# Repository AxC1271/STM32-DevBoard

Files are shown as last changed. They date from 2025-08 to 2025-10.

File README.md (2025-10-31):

# STM32 MCU Board

## 📖 Introduction
This repository is my first ever PCB design project. After working on projects that involved more digital circuits and RTL scripting, I've always wanted to build my own boards, specifically FPGA boards. However, I want to start on something simpler so I can understand the inner workings of PCB design, decision choices, and general concepts that are crucial to a functional STM32 board.

## 🛠️ Design Approach
Given that this is just a basic guide to designing, laying out, and manufacturing a simple STM32 board, this PCB will only offer a single USB port, an I2C interface, an SWD interface, and a UART interface. The specific processor chip that we are using is the STM32F103C8Tx, which uses an `ARM Cortex-M3 processor`. 

### ⚡ Power Regulator Circuit
<p align="center">
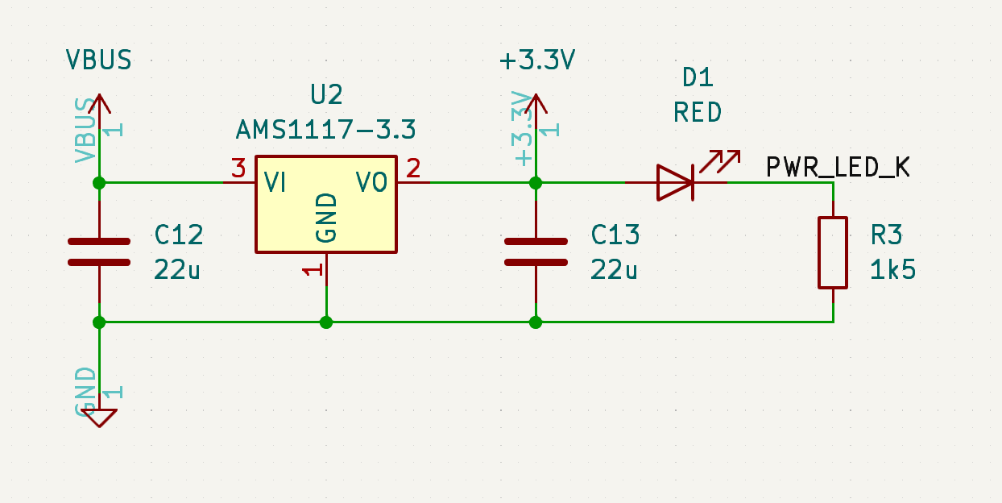
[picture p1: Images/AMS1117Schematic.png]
    
</p>
<p align="center">
    <em> LDO-Based Power Regulator Circuit.</em>
</p>

Here we have the external USB-B micro port that interfaces with our STM32 microcontroller. In order to use `VBUS` coming from this port, I stepped down any input voltage down to 3.3V using the **AMS1117** chip, which requires two `22uF` capacitors according to its datasheet, one at the input and one at the output. At the output, the 3.3V signal is then passed through an LED with a current limiting resistor as a visual indicator that the 3.3V source is present at the output.

<br />
Quick note about the shield option being ignored, generally the shield pin is to connect the board to an external chassis but because this is a standalone board, that's why it's ignored.

### 🔲 STM32F103C8T6 MCU
<p align="center">
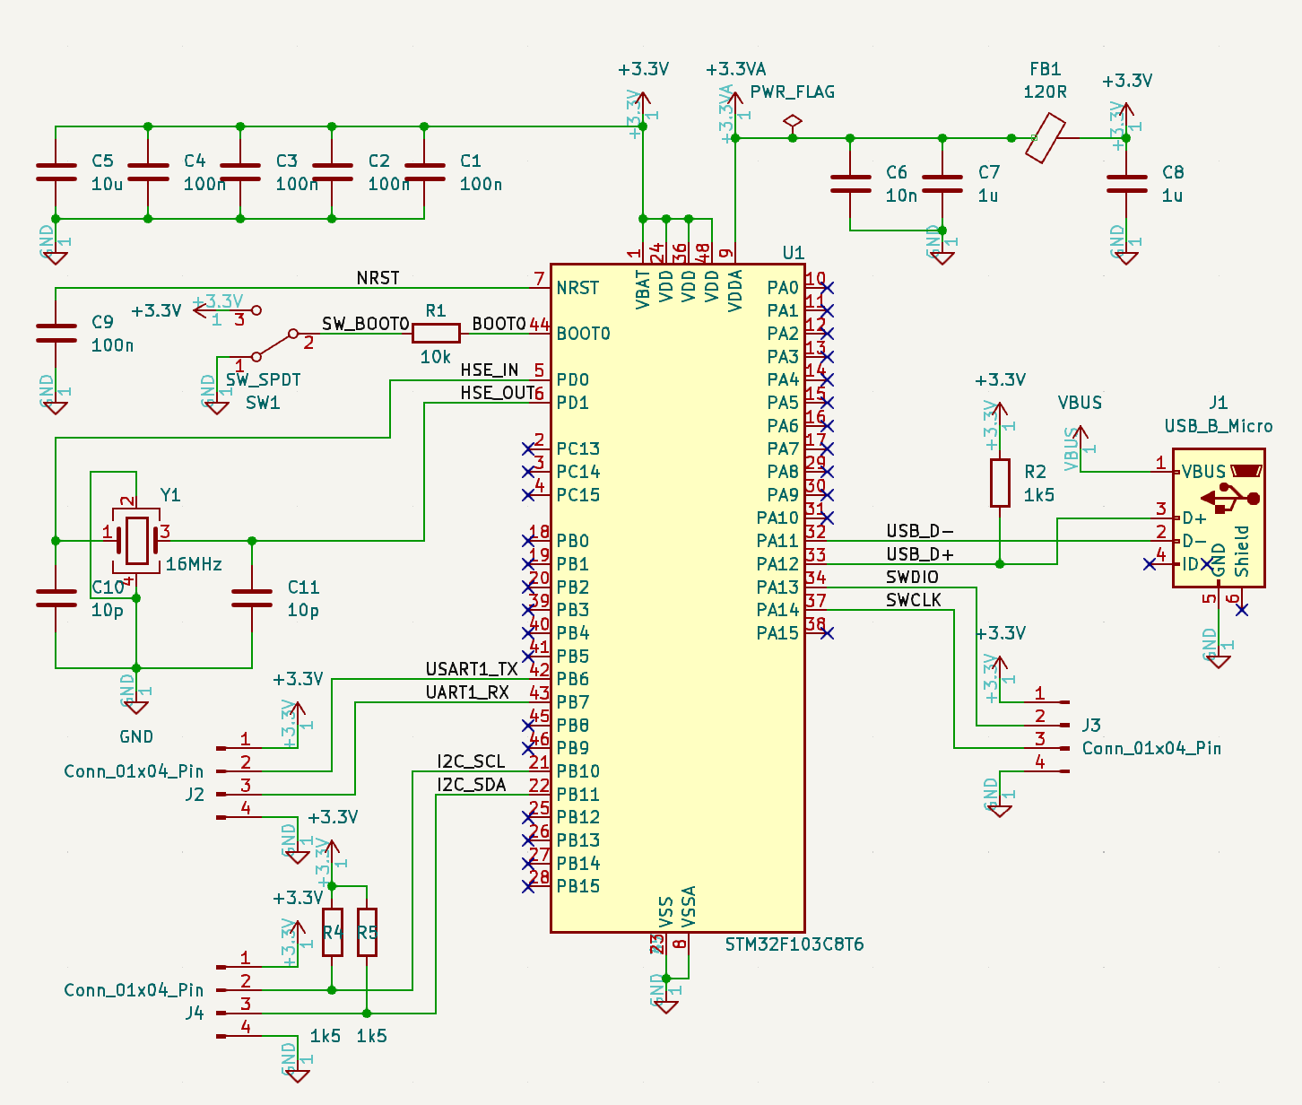
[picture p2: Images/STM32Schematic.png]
    
</p>
<p align="center">
    <em>MCU Schematic with USB-B Micro Interface.</em>
</p>

First and foremost, there needs to be capacitors between the 3.3V source and ground. Since this specific STM32 microcontroller has 4 **VDD** pins, there must generally be a `100 nF` capacitor in parallel for each of these pins. These capacitors act as `decoupling capacitors`, ensuring a steady voltage supply to each VDD pin. In addition, a bulk capacitor with a value of `4.7 uF` is also placed in parallel to the decoupling capacitors to handle lower-frequency current swings, while the decoupling capacitors handle the higher frequency noise and transients.

## 🧩 PCB Layout

<p align="center">
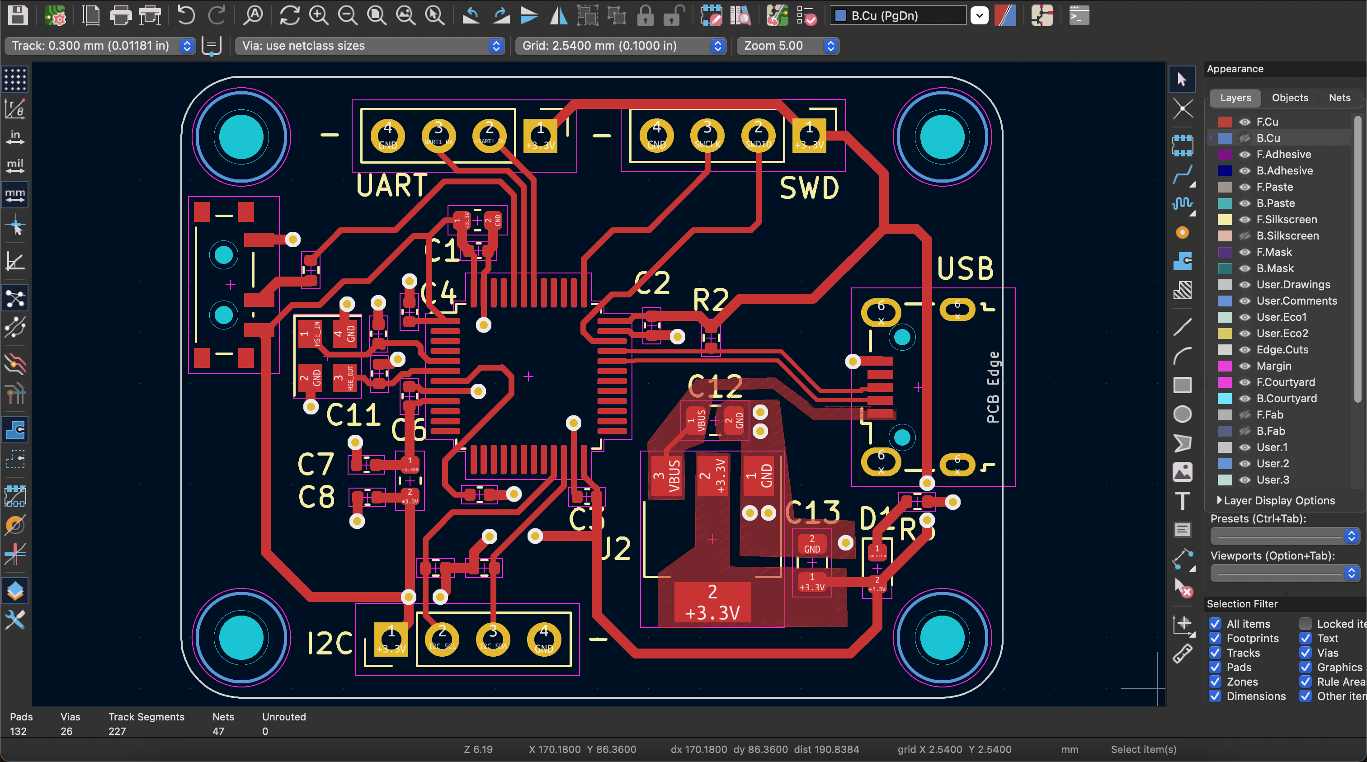
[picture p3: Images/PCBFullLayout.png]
    
</p>
<p align="center">
    <em> Signal traces on the STM32 board, with power traces being 0.5mm while ordinary traces are kept at 0.3mm. Vias are used for ground traces. </em>
</p>

In general, vias are used to link ground pins to the ground plane. Most signals are routed on the top copper layer, with a couple of vias used to prevent signal crossing especially with the 3.3V bus. 
A copper pour was used near the voltage regulator to create ground and power planes whilst also reducing EMI and improving signal integrity.

Quick note: to further increase the stability of a 2-layer board like this, it is recommended to add as much stitching vias as possible, on top of adding a ground pour on the top layer. This is to decrease
the distance that sensitive signals have to travel to get to ground, reducing the inductance and therefore maximizing signal integrity.

## 🖼️ 3D View

<p align="center">
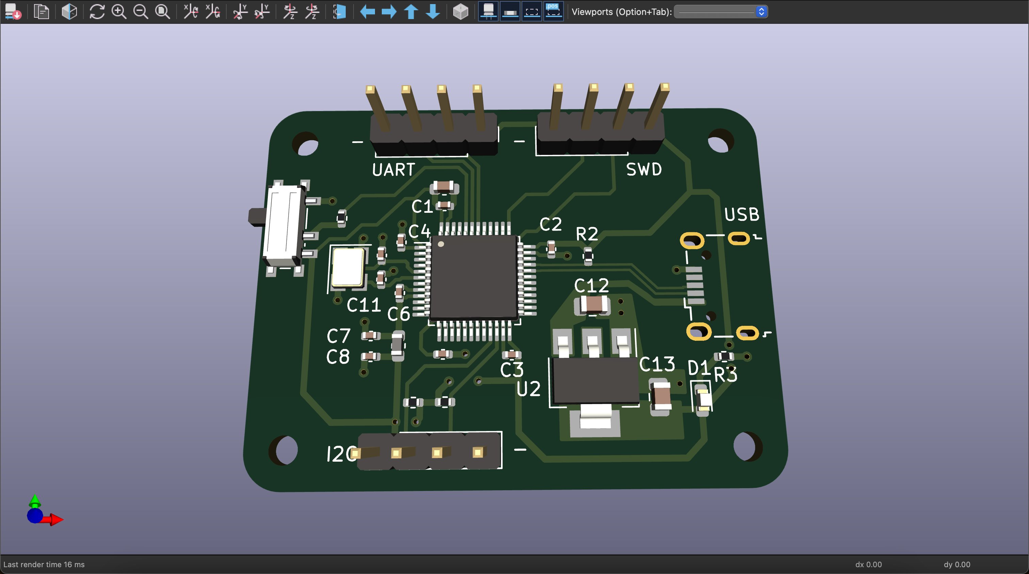
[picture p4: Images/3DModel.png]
    
</p>
<p align="center">
    <em> Front copper layer with all signal traces and silkscreens. </em>
</p>

## 🧪 Physical Board / Functionality

After passing a design rule check on KiCAD, it's time to send the files to a PCB manufacturer to get my board assembled. For this specific board, I'm using `JLCPCB`'s services to get my board manufactured. 

<p align="center">
    
</p>
<p align="center">
    <em>Manufactured Board from JLCPCB.</em>
</p>

Unfortunately, I was unable to find the USB micro-B ports for these boards, but I still want to be able to program it using an ST-Linker that I found off of Amazon for roughly `$9`. 

## 💻 Code

To test the UART interface of this STM32 board, I'll write a simple UART transceiver on my Basys3 FPGA board to interface with it.

UART Receiver:
```VHDL
library IEEE;
use IEEE.STD_LOGIC_1164.ALL;
use IEEE.NUMERIC_STD.ALL;

entity uart_rx is
    generic (
        clk_ticks: integer := 54 -- taken from (100_000_000 / 115200) / 16 = 54.25 ticks
        );
    port ( 
        clk : in STD_LOGIC;
        rst : in STD_LOGIC;
        rx : in STD_LOGIC;
        byte : out STD_LOGIC_VECTOR (7 downto 0);
        write : out STD_LOGIC
        );
end uart_rx;

architecture Behavioral of uart_rx is
    -- define internal signals here
    type rx_state is (IDLE, START, DATA, STOP); -- defined states
    signal curr_state : rx_state := IDLE; -- initial state
    
    signal baud_clk : STD_LOGIC := '0';
    signal byte_i : STD_LOGIC_VECTOR(7 downto 0) := (others => '0');
    
begin
    -- define internal processes here
    
    -- first process is a clock generator that generates an oversampled
    -- clock signal to check for the rx signal
    clk_generator : process(clk, rst) 
        variable clk_count : integer range 0 to clk_ticks := 0;
    begin 
        if rst = '1' then
            clk_count := 0;
            baud_clk <= '0';
        elsif rising_edge(clk) then
            if clk_count = clk_ticks then
                clk_count := 0;
                baud_clk <= '1'; -- set high when clk count reaches 54
            else
                clk_count := clk_count + 1;
                baud_clk <= '0';
            end if;
        end if;
    end process;
    
    -- second process handles the state machine logic
    rx_FSM : process(clk, rst) 
        variable bit_count : integer range 0 to 7 := 0; -- check for where we are in the data word
        variable bit_duration : integer range 0 to 15 := 0; -- check if a logic level has stayed steady
    begin
        if rst = '1' then
            byte_i <= (others => '0'); -- reset data bus
            curr_state <= IDLE;
            bit_count := 0;
            bit_duration := 0;
            write <= '0';
        elsif rising_edge(clk) then
            if baud_clk = '1' then
                case curr_state is
                    when IDLE =>
                        byte_i <= (others => '0');
                        bit_count := 0;
                        bit_duration := 0;
                        write <= '0';
                        -- if the rx line gets pulled low then
                        if rx = '0' then
                            curr_state <= START;
                        end if;
                    when START =>
                        write <= '0';
                        if rx = '0' then
                            if bit_duration = 7 then
                                curr_state <= DATA;
                                bit_duration := 0;
                            else
                                bit_duration := bit_duration + 1;
                            end if;
                        else
                            curr_state <= IDLE;
                        end if;
                    when DATA =>
                        write <= '0';
                        if (bit_duration = 15) then                
                                byte_i(bit_count) <= rx;     
                                bit_duration := 0;
                                if (bit_count = 7) then -- we got 8 bits             
                                    curr_state <= STOP;
                                    bit_duration := 0;
                                else
                                    bit_count := bit_count + 1;
                                end if;
                            else
                                bit_duration := bit_duration + 1;
                            end if;
                    when STOP =>
                        if (bit_duration = 15) then      
                            if rx = '1' then  -- validate stop bit is HIGH
                                byte <= byte_i;
                                write <= '1';    
                                curr_state <= IDLE;
                            else
                            -- Invalid stop bit, frame error - reset
                                curr_state <= IDLE;
                            end if;
                        else
                            bit_duration := bit_duration + 1;
                        end if;
                    when others =>
                        curr_state <= IDLE;
                end case;
            end if;
        end if;
    end process;

end Behavioral;
```

Now we can write the C++ code for the STM32 to pass in some serial data to the Basys3 board and vice versa. We will interface using PlatformIO and write some firmware for the STM32 to transmit some characters to the FPGA. This is just one test code example:

```C++
#include <Arduino.h>
#include <HardwareSerial.h>

// TX pin: PB6, RX pin: PB7 (for UART1)
HardwareSerial Serial1(PB7, PB6); // RX, TX pins

unsigned long lastByteTime = 0;
const unsigned long byteInterval = 1000; // send each byte every 1 second
const char message[] = "Hello "; // message to send
int currentByteIndex = 0;
const int messageLength = 6; 

void setup() {
  Serial1.begin(115200); // uart receiver has baud rate of 115200
  
  Serial.begin(115200);
  Serial.println("STM32 UART Transmitter Started");
  Serial.println("Transmitting 'Hello' - one byte per second");

}

void loop() {
  if (millis() - lastByteTime >= byteInterval) {
    
    char currentByte = message[currentByteIndex];
    Serial1.write(currentByte);
    
    Serial.print("Transmitted byte: '");
    Serial.print(currentByte);
    Serial.print("' (ASCII: ");
    Serial.print((int)currentByte);
    Serial.println(")");

    digitalWrite(PC13, !digitalRead(PC13));
    
    currentByteIndex++;
    if (currentByteIndex >= messageLength) {
      currentByteIndex = 0; 
      Serial.println("--- Message complete, restarting ---");
    }
    
    lastByteTime = millis();
  }
  
  delay(10);
}
```

## 🎥 Video Demo

The first **[video demo](https://youtube.com/shorts/mgw7LnCIHqA)**  shows the FPGA receiver interacting with my Macbook via the `USB-to-Serial bridge`. The purpose of this
is to see the board behaving correctly from a known source using the terminal. Once the receiver's behavior has been validated,
then we can integrate the STM32 board and test its functionality.

Here's the **[video demo](https://youtube.com/shorts/DqSGexJcCeM)** showing the Basys3 taking the data bytes through a PMOD port from the STM32 MCU board to show that communication is 
indeed possible from my fabricated board. This required changing the RX pin on the FPGA to receive the byte.

---

Thanks for stopping and reading until the very end and I hope you learned something new from this README file!

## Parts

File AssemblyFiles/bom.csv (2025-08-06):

Comment | Designator | Footprint | LCSC Part # | Quantity
100nF | C1 C2 C3 C4 C9 | C_0402_1005Metric | C1525 | 5
10uF | C5 | C_0603_1608Metric | C19702 | 1
10nF | C6 | C_0402_1005Metric | C15195 | 1
1uF | C7 C8 | C_0402_1005Metric | C52923 | 2
10pF | C10 C11 | C_0402_1005Metric | C32949 | 2
22uF | C12 C13 | C_0805_2012Metric | C45783 | 2
RED LED | D1 | LED_0603_1608Metric | C2286 | 1
120R@100MHz Ferrite Bead | FB1 | L_0603_1608Metric | C1030 | 1
USB Micro-B | J1 | USB_Micro-B_Wuerth_629105150521 | C132563 | 1
1x4 2.54mm Pin Header | J2 J3 J4 | PinHeader_1x04_P2.54mm_Vertical | C124378 | 3
10kΩ | R1 | R_0402_1005Metric | C25744 | 1
1.5kΩ | R2 R3 R4 R5 | R_0402_1005Metric | C25867 | 4
SPDT Slide Switch | SW1 | SW_SPDT_PCM12 | C221841 | 1
STM32F103C8T6 | U1 | LQFP-48_7x7mm_P0.5mm | C8734 | 1
AMS1117-3.3V | U2 | SOT-223-3_TabPin2 | C6186 | 1
16MHz Crystal 4-pin | Y1 | Crystal_SMD_3225-4Pin_3.2x2.5mm | C13738 | 1

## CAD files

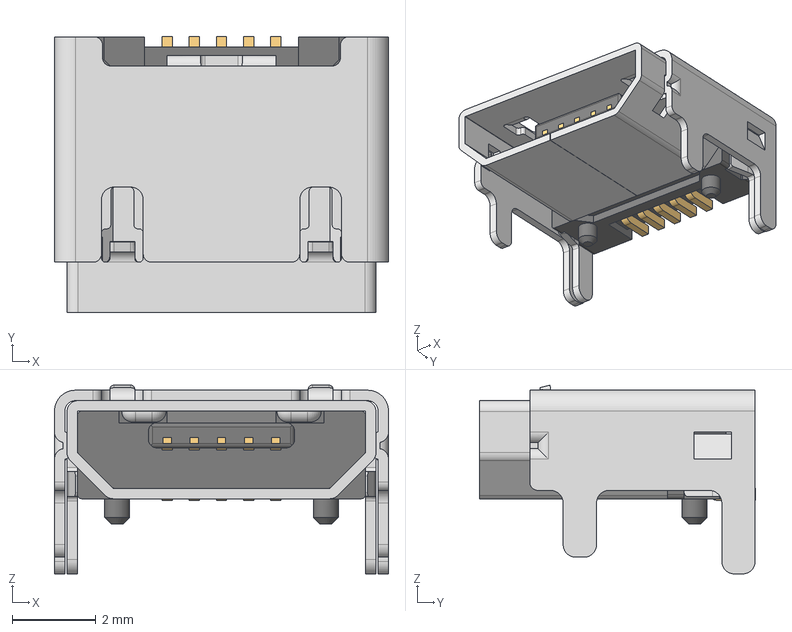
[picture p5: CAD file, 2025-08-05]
KiCADFiles/629105150521 (rev1).stp
8.00 x 6.60 x 4.52 mm
629105150521_Housing
629105150521_Pin1 x 4
629105150521_Pin2
629105150521_Shielding2
629105150521_Shielding

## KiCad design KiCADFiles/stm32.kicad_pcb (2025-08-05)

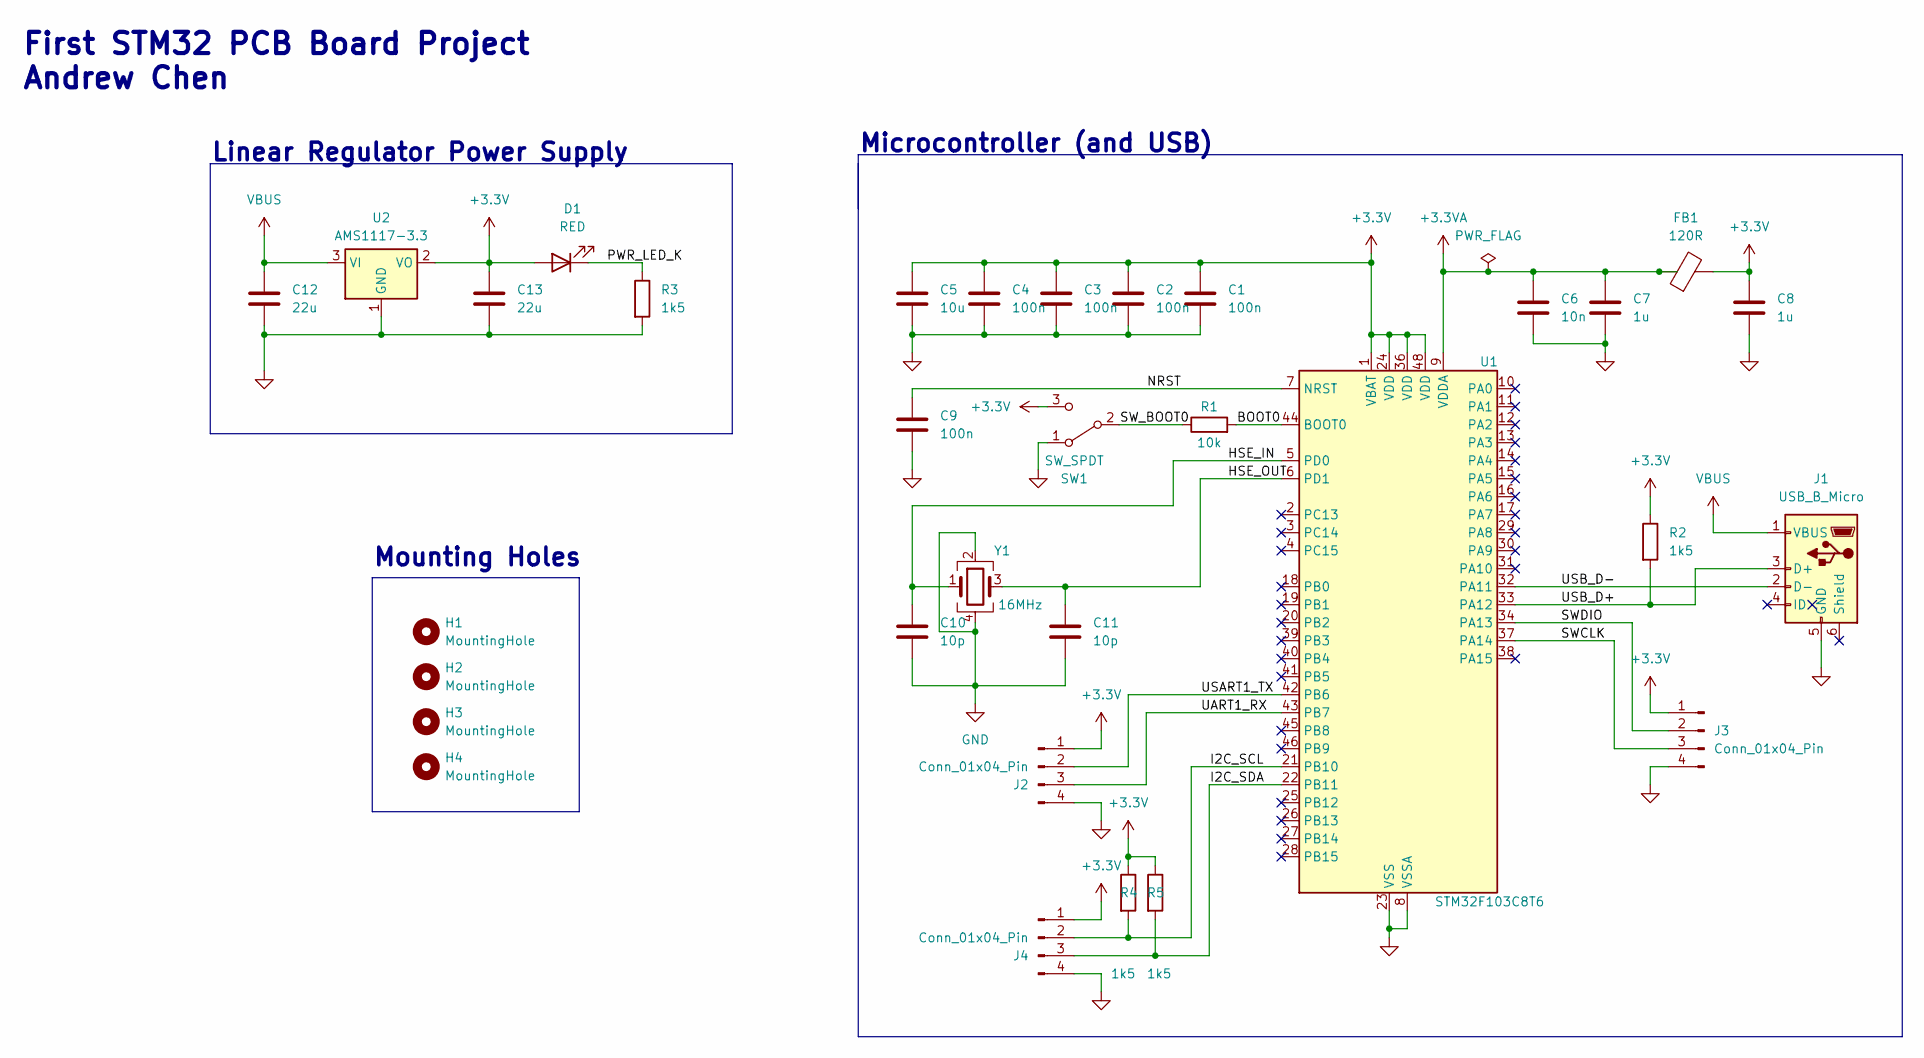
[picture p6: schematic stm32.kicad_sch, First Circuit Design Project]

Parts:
C1, C2, C3, C4, C9: 100n; C_0402_1005Metric
C5: 10u; C_0603_1608Metric
C6: 10n; C_0402_1005Metric
C7, C8: 1u; C_0402_1005Metric
C10, C11: 10p; C_0402_1005Metric
C12, C13: 22u; C_0805_2012Metric
D1: RED; LED_0603_1608Metric
FB1: 120R; L_0603_1608Metric
H1, H2, H3, H4: MountingHole; MountingHole_2.2mm_M2
J1: USB_B_Micro; USB_Micro-B_Wuerth_629105150521
J2, J3, J4: Conn_01x04_Pin; PinHeader_1x04_P2.54mm_Vertical
R1: 10k; R_0402_1005Metric
R2, R3, R4, R5: 1k5; R_0402_1005Metric
SW1: SW_SPDT; SW_SPDT_PCM12
U1: STM32F103C8T6; LQFP-48_7x7mm_P0.5mm
U2: AMS1117-3.3; SOT-223-3_TabPin2
Y1: 16MHz; Crystal_SMD_3225-4Pin_3.2x2.5mm

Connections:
+3.3V: C1.1, C2.1, C3.1, C4.1, C5.1, C8.1, C13.1, D1.2 (A), FB1.2, J2.1, J3.1, J4.1, R2.1, R4.1, R5.1, SW1.3 (C), U1.1 (VBAT), U1.24 (VDD), U1.36 (VDD), U1.48 (VDD), U2.2 (VO)
+3.3VA: C6.1, C7.1, FB1.1, U1.9 (VDDA)
/BOOT0: R1.2, U1.44 (BOOT0)
/HSE_IN: C10.1, U1.5 (PD0), Y1.1
/HSE_OUT: C11.1, U1.6 (PD1), Y1.3
/I2C_SCL: J4.2, R4.2, U1.21 (PB10)
/I2C_SDA: J4.3, R5.2, U1.22 (PB11)
/NRST: C9.1, U1.7 (NRST)
/PWR_LED_K: D1.1 (K), R3.1
/SWCLK: J3.3, U1.37 (PA14)
/SWDIO: J3.2, U1.34 (PA13)
/SW_BOOT0: R1.1, SW1.2 (B)
/UART1_RX: J2.3, U1.43 (PB7)
/USART1_TX: J2.2, U1.42 (PB6)
/USB_D+: J1.3 (D+), R2.2, U1.33 (PA12)
/USB_D-: J1.2 (D-), U1.32 (PA11)
GND: C1.2, C2.2, C3.2, C4.2, C5.2, C6.2, C7.2, C8.2, C9.2, C10.2, C11.2, C12.2, C13.2, J1.5 (GND), J2.4, J3.4, J4.4, R3.2, SW1.1 (A), U1.8 (VSSA), U1.23 (VSS), U1.35 (VSS), U1.47 (VSS), U2.1 (GND), Y1.2, Y1.4
VBUS: C12.1, J1.1 (VBUS), U2.3 (VI)

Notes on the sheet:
Mounting Holes
Microcontroller (and USB)
Linear Regulator Power Supply
First STM32 PCB Board Project Andrew Chen

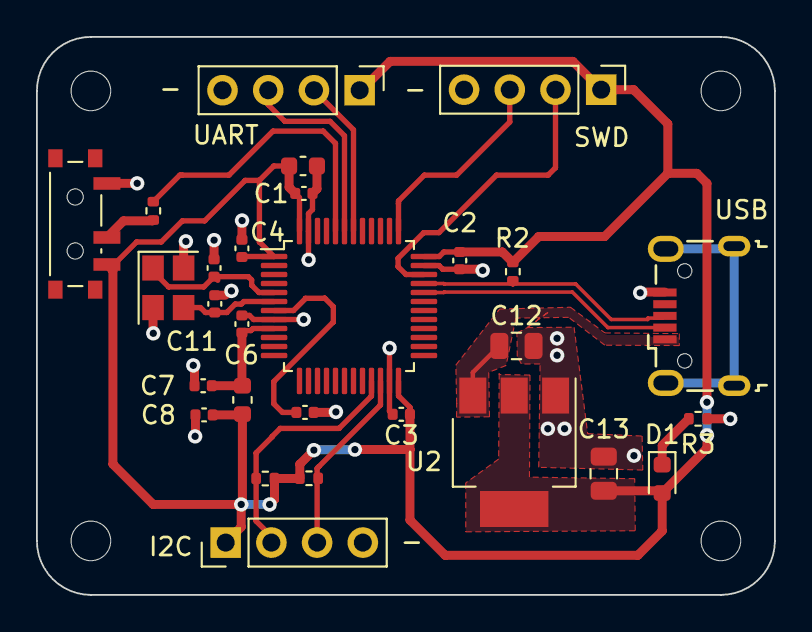
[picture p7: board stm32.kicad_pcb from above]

Board: 2 copper layers, 41.0 x 31.0 mm, 32 parts (0 on the bottom side), 18 nets.

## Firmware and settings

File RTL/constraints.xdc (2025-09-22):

set_property PACKAGE_PIN W5 [get_ports clk]
set_property IOSTANDARD LVCMOS33 [get_ports clk]
create_clock -period 10.0 -name sys_clk -waveform {0.0 5.0} [get_ports clk]

set_property PACKAGE_PIN U18 [get_ports rst]
set_property IOSTANDARD LVCMOS33 [get_ports rst]

set_property PACKAGE_PIN J1 [get_ports rx]
set_property IOSTANDARD LVCMOS33 [get_ports rx]

set_property PACKAGE_PIN U16 [get_ports {data[0]}]
set_property IOSTANDARD LVCMOS33 [get_ports {data[0]}]

set_property PACKAGE_PIN E19 [get_ports {data[1]}]
set_property IOSTANDARD LVCMOS33 [get_ports {data[1]}]

set_property PACKAGE_PIN U19 [get_ports {data[2]}]
set_property IOSTANDARD LVCMOS33 [get_ports {data[2]}]

set_property PACKAGE_PIN V19 [get_ports {data[3]}]
set_property IOSTANDARD LVCMOS33 [get_ports {data[3]}]

set_property PACKAGE_PIN W18 [get_ports {data[4]}]
set_property IOSTANDARD LVCMOS33 [get_ports {data[4]}]

set_property PACKAGE_PIN U15 [get_ports {data[5]}]
set_property IOSTANDARD LVCMOS33 [get_ports {data[5]}]

set_property PACKAGE_PIN U14 [get_ports {data[6]}]
set_property IOSTANDARD LVCMOS33 [get_ports {data[6]}]

set_property PACKAGE_PIN V14 [get_ports {data[7]}]
set_property IOSTANDARD LVCMOS33 [get_ports {data[7]}]

set_property IOSTANDARD LVCMOS33 [get_ports seg[0]]
set_property IOSTANDARD LVCMOS33 [get_ports seg[1]]
set_property IOSTANDARD LVCMOS33 [get_ports seg[2]]
set_property IOSTANDARD LVCMOS33 [get_ports seg[3]]
set_property IOSTANDARD LVCMOS33 [get_ports seg[4]]
set_property IOSTANDARD LVCMOS33 [get_ports seg[5]]
set_property IOSTANDARD LVCMOS33 [get_ports seg[6]]

set_property PACKAGE_PIN U7 [get_ports seg[0]]
set_property PACKAGE_PIN V5 [get_ports seg[1]]
set_property PACKAGE_PIN U5 [get_ports seg[2]]
set_property PACKAGE_PIN V8 [get_ports seg[3]]
set_property PACKAGE_PIN U8 [get_ports seg[4]]
set_property PACKAGE_PIN W6 [get_ports seg[5]]
set_property PACKAGE_PIN W7 [get_ports seg[6]]

set_property IOSTANDARD LVCMOS33 [get_ports ade[0]]
set_property IOSTANDARD LVCMOS33 [get_ports ade[1]]
set_property IOSTANDARD LVCMOS33 [get_ports ade[2]]
set_property IOSTANDARD LVCMOS33 [get_ports ade[3]]

set_property PACKAGE_PIN U2 [get_ports ade[0]]
set_property PACKAGE_PIN U4 [get_ports ade[1]]
set_property PACKAGE_PIN V4 [get_ports ade[2]]
set_property PACKAGE_PIN W4 [get_ports ade[3]]

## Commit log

2025-08-17 Update and rename uart_rx.vhd to uart_rx.v
2025-09-22 Update and rename uart_controller.vhd to uart_controller.v
2025-10-31 Update and rename uart_controller.v to uart_controller.vhd
2025-10-31 Implement UART receiver in VHDL
2025-10-31 Convert UART receiver from Verilog to VHDL
    Updated UART receiver implementation from Verilog to VHDL, including state machine and clock generator processes.
